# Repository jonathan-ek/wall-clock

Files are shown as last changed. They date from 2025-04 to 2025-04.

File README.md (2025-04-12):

# Wall clock
Smart wall clock that displays the electricity price
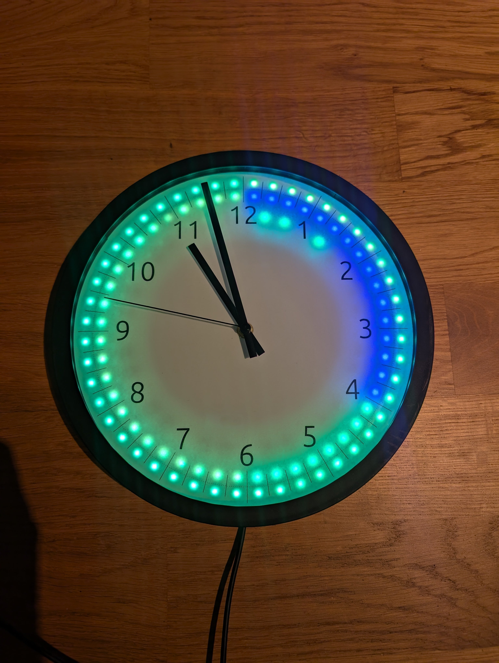
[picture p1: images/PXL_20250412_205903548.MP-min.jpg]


## Bill of material:
* Amazon Basics wall clock
* NeoPixel led strip 144 pixels per meter. Each pixel where 12 mm high and 7 mm wide
* Raspberry pi Pico W
* USB power supply + cable
* Transparent plastic sheet 300 x 300 x 3 mm
* Some black PLA or your material of choice
* Copper wire
* Solder

For a total cost of around 500-600 SEK plus some shipping

## Steps:
* Read the instructions and the comments
* Print the 3d printed parts
  * The fit of the printed parts isn't perfect, but it was good enough to not warrant any changes.
    You will need to print 4 of each 3d part.
    I welded the backplate parts together with a soldering iron, and some more filament.
    The other parts I just added a bit of glue between them and a round of electrical tape around the piece.
 
* Cut the LED strip in pieces so that there is one led per piece
* Print the LED placement guide and glue it to the backplate
* Glue the LEDs to the placement guide
* Solder the wires to the LEDs (this will take a while)
  * I would suggest testing the work as you go, so that you don't have to redo the whole thing if something goes wrong.
  * Start at 12 o'clock and go clockwise around the clock, after the outer ring is done, go from the last led to the inner ring and repeat
* Solder the wires to the Pico W, I used GP0, VBUS and GND
* Cut the plastic sheet to size
* Print the clock face and drill a 8 mm hole in the middel through the face and the plastic sheet
* Assemble the clock
  * Fasten the clock face to the plastic sheet with a few small tape pieces on the edges
  * Add the clock mechanism to the plastic sheet and reattach the clock hands
  * Then add the parts in the correct order:
    * Glass
    * Glass holder
    * Clock face
    * Backplate with LEDs
    * Outer ring
* Glue the Pico W to the backplate so that it is still accessible but not sticking out too much so it hits the wall.
* Melt a hole in the side of the clock housing for the power cable
* Optional glue the cable to the backplate so it doesn't move around too much
* Upload the code to the Pico W
* Add the home assistant file as a [python script](https://www.home-assistant.io/integrations/python_script/) and adjust it to your needs and sensors.

# Images:
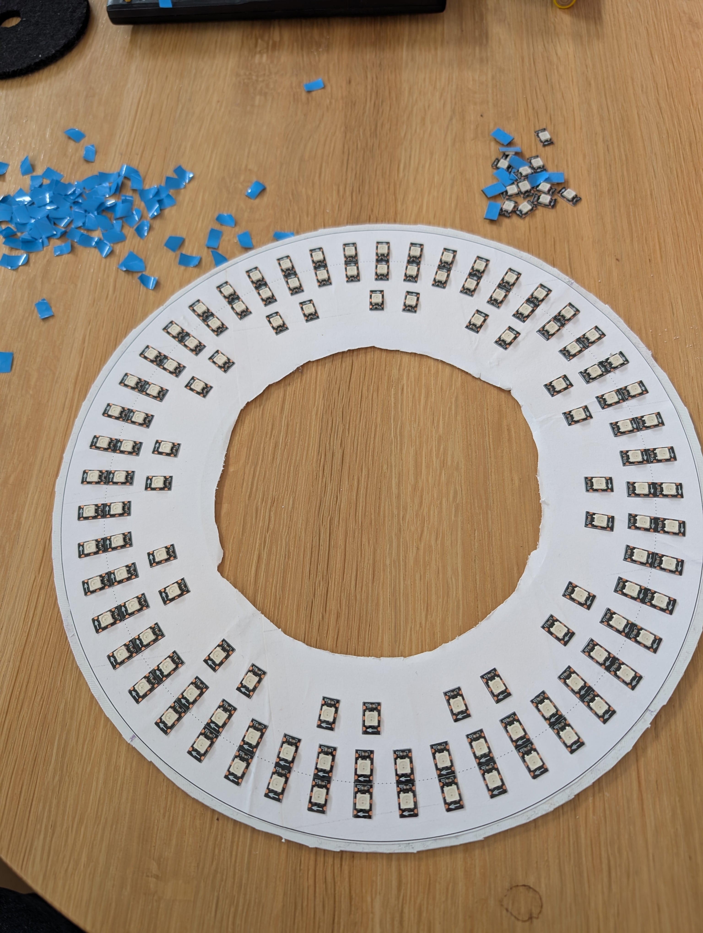
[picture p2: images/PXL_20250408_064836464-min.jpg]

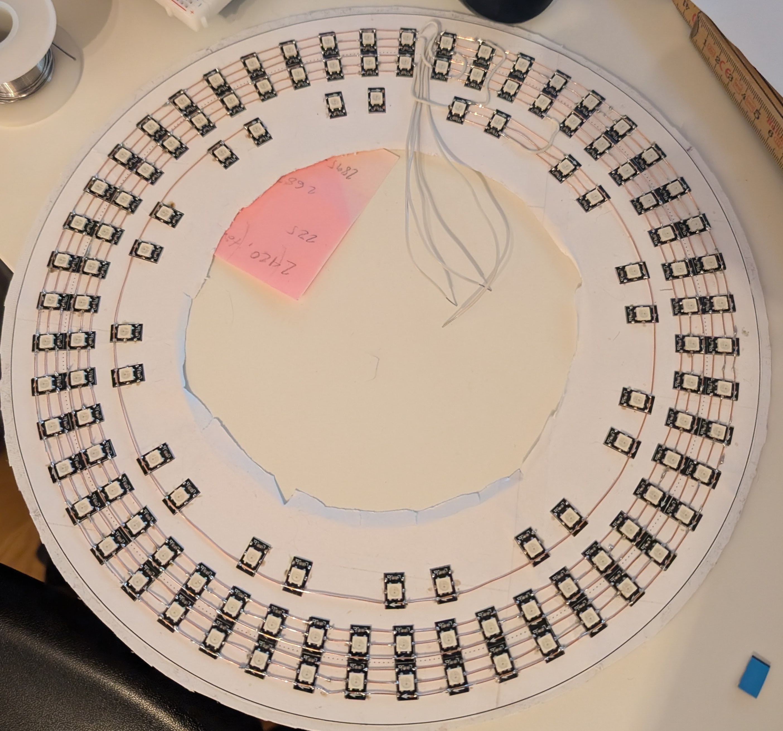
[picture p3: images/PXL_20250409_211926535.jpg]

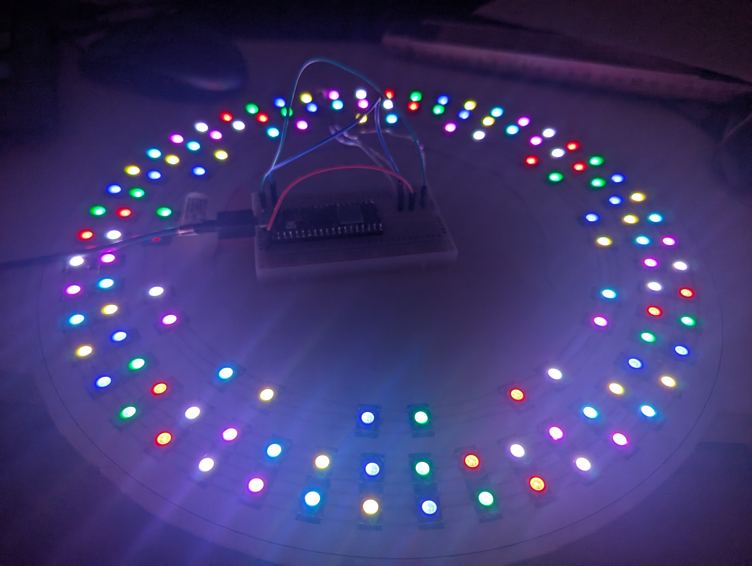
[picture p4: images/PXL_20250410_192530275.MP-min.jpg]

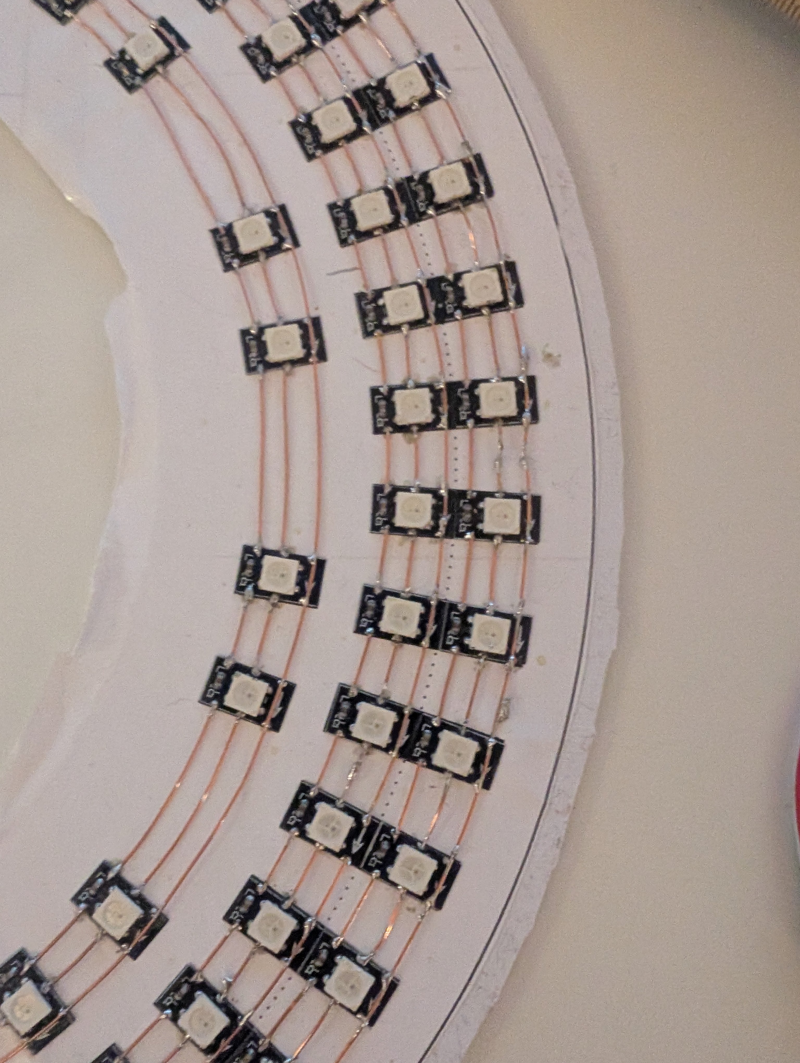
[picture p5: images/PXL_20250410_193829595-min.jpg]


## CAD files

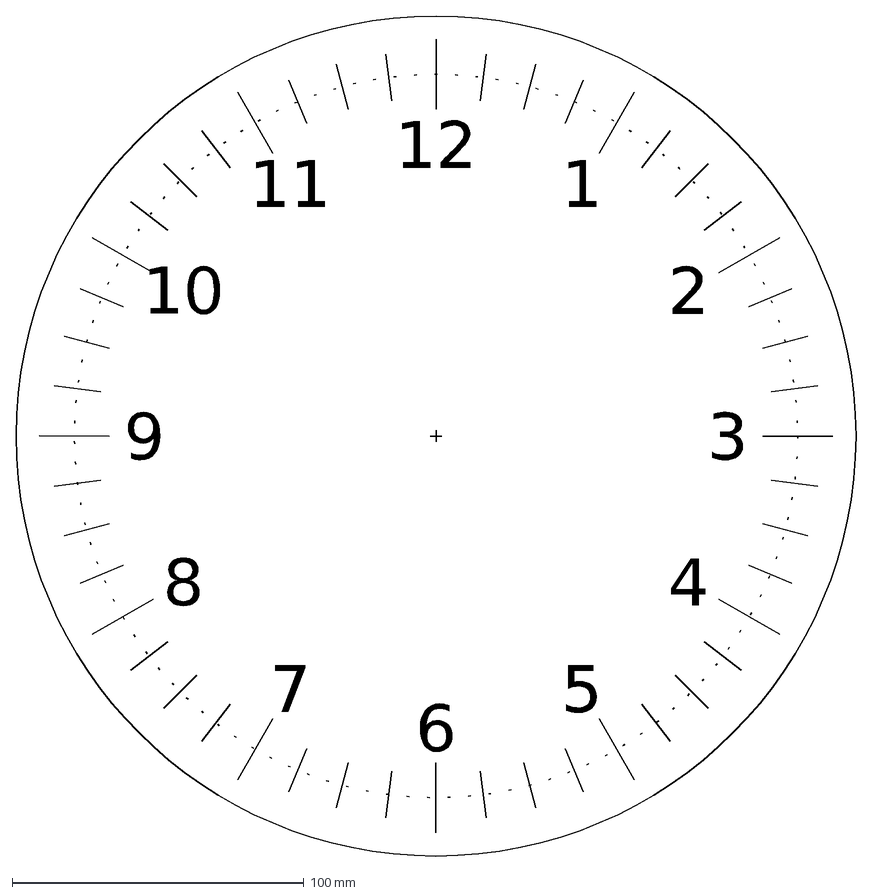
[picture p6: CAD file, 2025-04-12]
CAD-files/clock.dxf
12
11
10
9
8
7
6
5
4
3
2
1

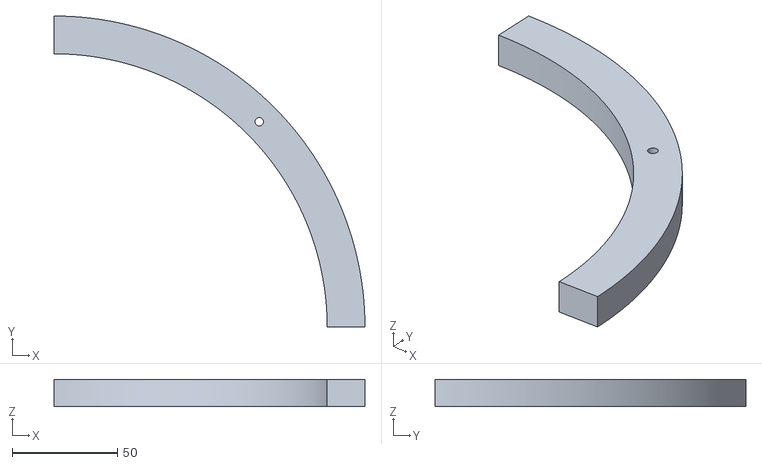
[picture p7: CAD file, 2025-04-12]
Output/outer_ring.stl
148.0 x 148.0 x 13.0

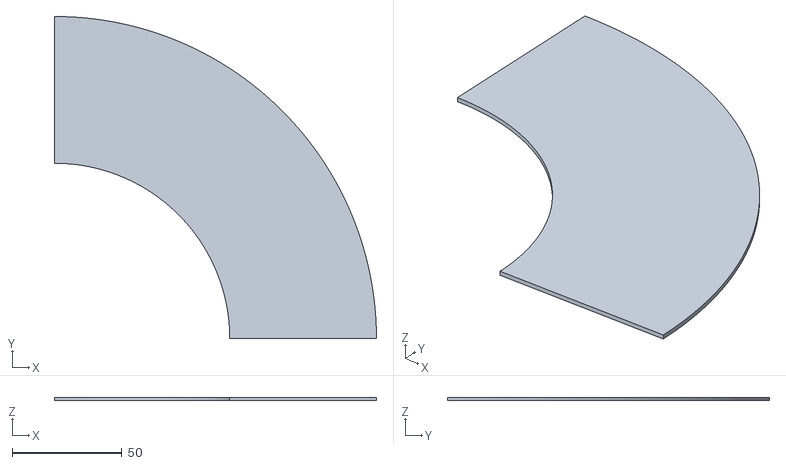
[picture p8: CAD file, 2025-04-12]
Output/back_plate.stl
147.0 x 147.0 x 1.50

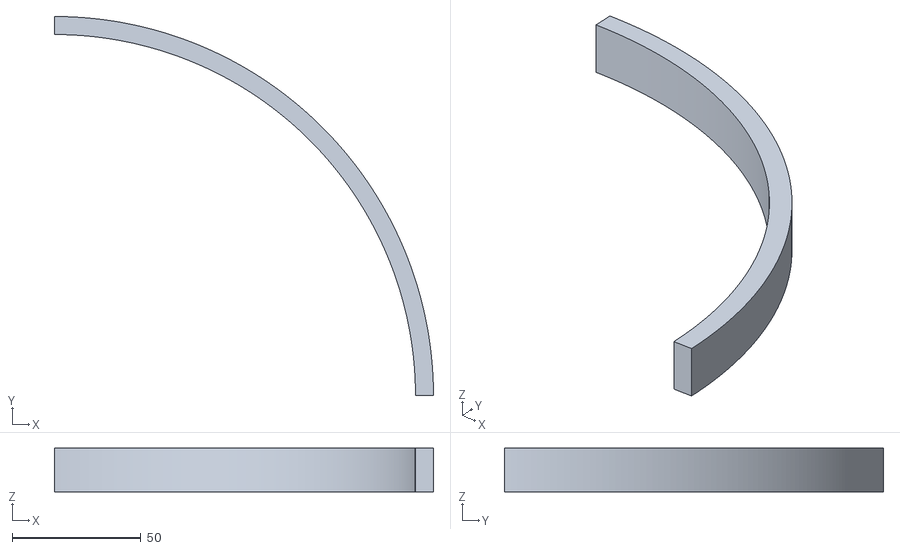
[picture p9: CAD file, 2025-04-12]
Output/glas_holder.stl
147.0 x 147.0 x 17.0

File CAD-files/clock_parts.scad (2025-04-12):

outer_dia = 296;

module glas_holder(){
    difference() {
        difference() {
            cylinder(17,r=outer_dia/2,$fn=360);
            translate([0,0,-1]){
                cylinder(19,r=280/2,$fn=720);
            }
        }
        union() {
            translate([-151,-151,-1]){
                cube([151,301,20]);
            }
            translate([-151,-151,-1]){
                cube([301,151,20]);
            }
        }
    }
}

module front_plate(){
    difference() {
        difference() {
            cylinder(1.5,r=outer_dia/2,$fn=360);
            translate([0,0,-1]){
                cylinder(19,r=8/2,$fn=720);
            }
        }
        union() {
            translate([-151,-151,-1]){
                cube([151,301,20]);
            }
            translate([-151,-151,-1]){
                cube([301,151,20]);
            }
        }
    }
}

module back_plate(){
    difference() {
        difference() {
            cylinder(1.5,r=outer_dia/2,$fn=360);
            translate([0,0,-1]){
                cylinder(19,r=160/2,$fn=720);
            }
        }
        union() {
            translate([-151,-151,-1]){
                cube([151,301,20]);
            }
            translate([-151,-151,-1]){
                cube([301,151,20]);
            }
        }
    }
}

module outer_ring(){
    difference() {
        difference() {
            cylinder(13,r=outer_dia/2,$fn=360);
            translate([0,0,-1]){
                cylinder(19,r=260/2,$fn=720);
                translate([(outer_dia/2)*0.66,(outer_dia/2)*0.66,0]) {
                    
                    cylinder(19,r=2,$fn=100);
                }
            }
            
        }
        
        union() {
            translate([-151,-151,-1]){
                cube([151,301,20]);
            }
            translate([-151,-151,-1]){
                cube([301,151,20]);
            }
        }
    }
}

//glas_holder();
//front_plate();
//back_plate();
outer_ring();

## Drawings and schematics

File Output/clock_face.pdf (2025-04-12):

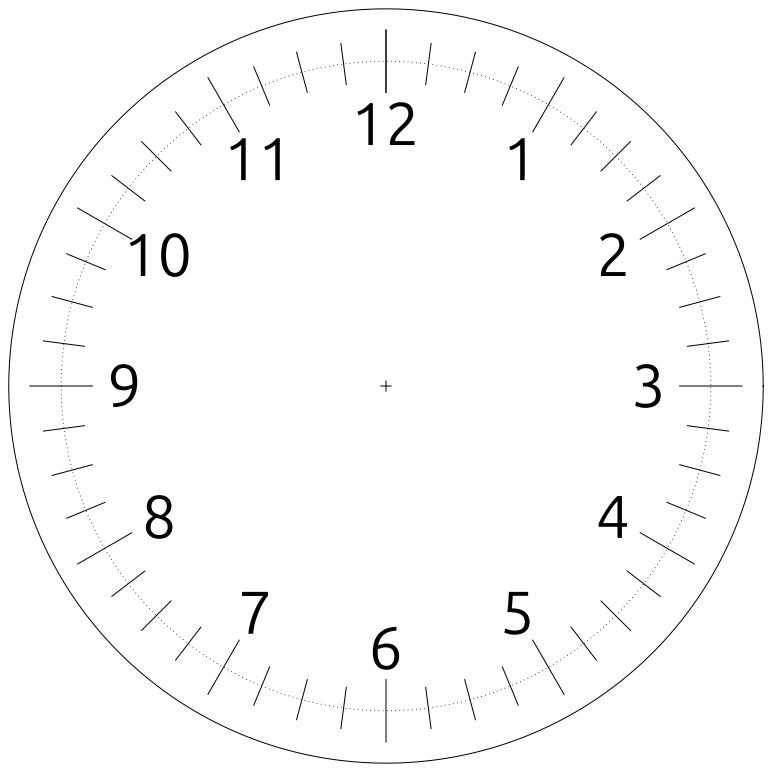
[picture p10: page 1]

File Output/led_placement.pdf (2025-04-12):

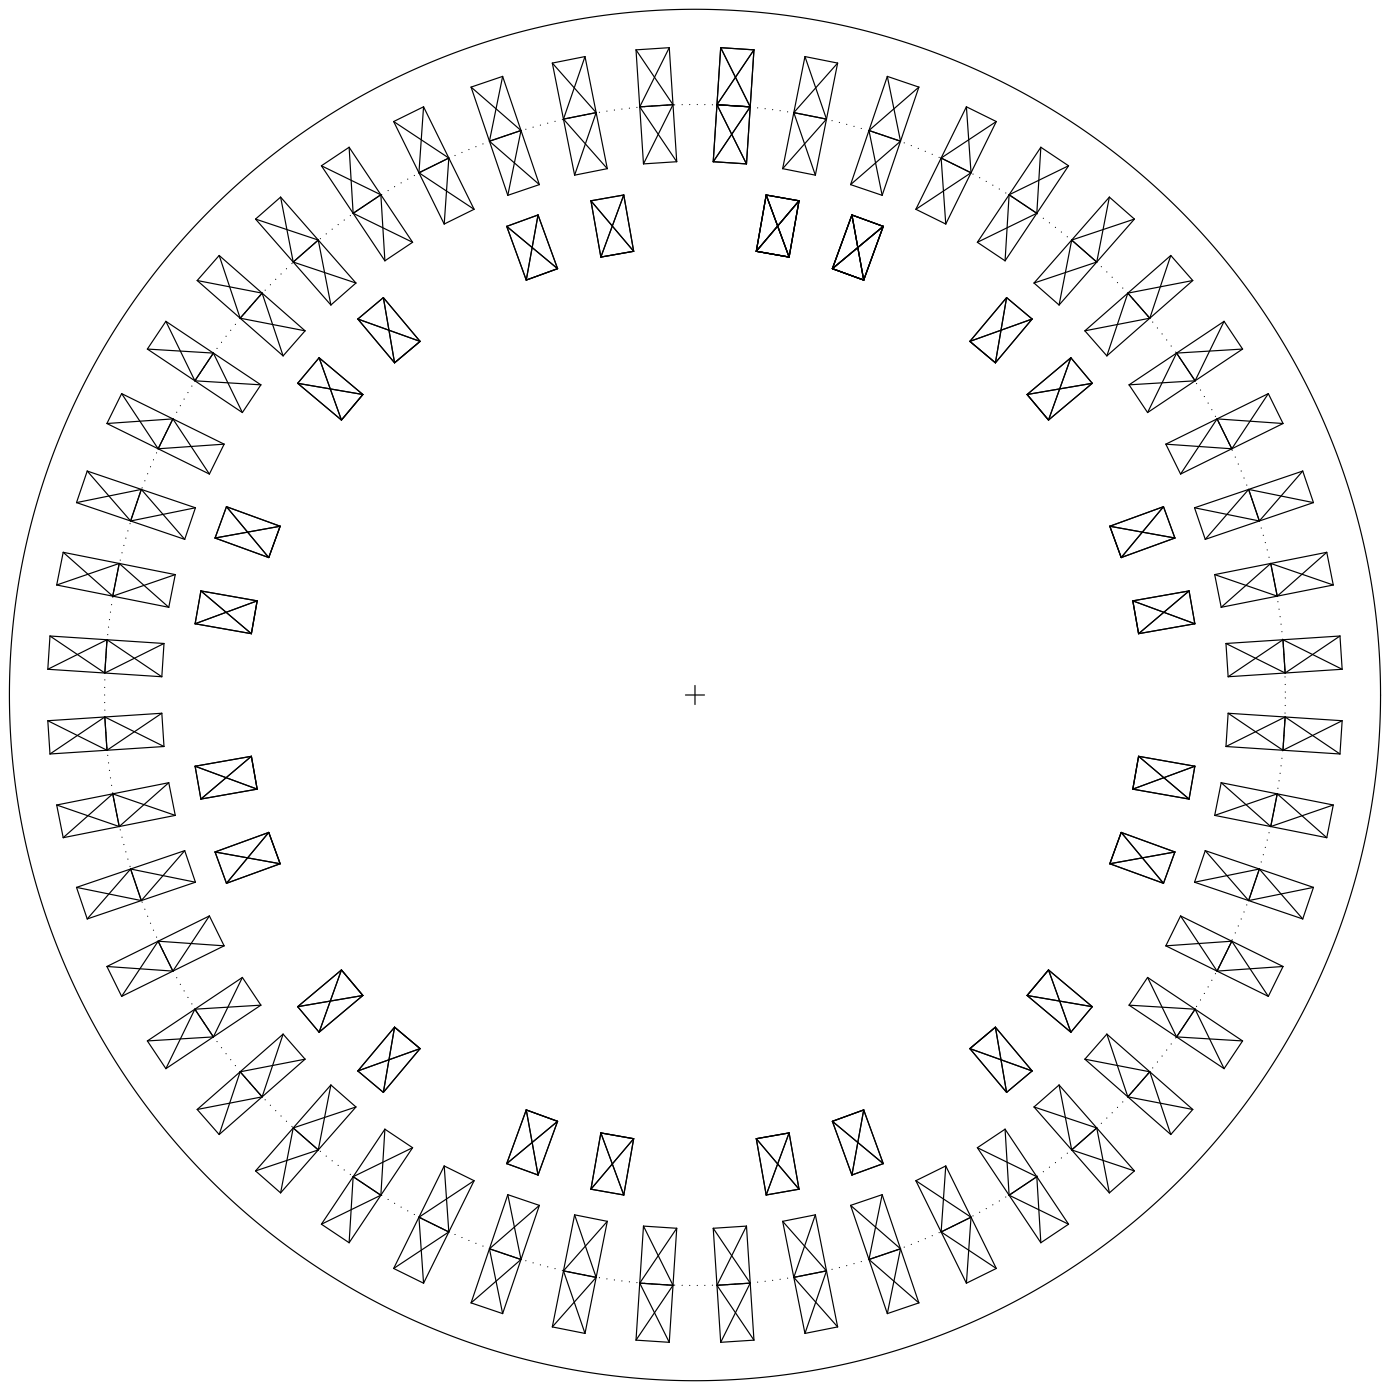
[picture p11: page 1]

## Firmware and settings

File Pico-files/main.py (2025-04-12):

import network
import uasyncio as asyncio
import urequests as requests
import neopixel
import machine
import time
from config import SSID, PSK, ENDPOINT, TOKEN
LED_PIN = 0  # GPIO pin
NUM_LEDS = 120

# SETUP NEOPIXEL
np = neopixel.NeoPixel(machine.Pin(LED_PIN), NUM_LEDS)

# GLOBAL STATE
current_state = [((0, 0, 0), "solid") for _ in range(NUM_LEDS)]

# CONNECT TO WIFI
def connect_wifi():
    wlan = network.WLAN(network.STA_IF)
    wlan.active(True)
    if not wlan.isconnected():
        print("Connecting to WiFi...")
        wlan.connect(SSID, PSK)
        while not wlan.isconnected():
            time.sleep(0.5)
    print("Connected:", wlan.ifconfig())

# UPDATE LEDS BASED ON STATE
def update_leds():
    for i, (rgb, mode) in enumerate(current_state):
        np[i] = rgb if mode == "solid" else (0, 0, 0)  # pulsing handled separately
    np.write()

# PULSING EFFECT TASK
async def pulsing_effect():
    while True:
        for brightness in list(range(0, 256, 15)) + list(range(255, -1, -15)):
            for i, (rgb, mode) in enumerate(current_state):
                if mode == "pulsing":
                    scaled = tuple(int(c * (brightness / 255)) for c in rgb)
                    np[i] = scaled
            np.write()
            await asyncio.sleep(0.05)

# FETCH COLORS FROM API
async def fetch_and_update():
    global current_state
    while True:
        try:
            print("Sending POST request...")
            response = requests.post(ENDPOINT, headers={
                "Authorization": f"Bearer {TOKEN}"
                })
            if response.status_code == 200:
                data = response.json().get("service_response", {}).get('data', [])
                if isinstance(data, list) and len(data) == NUM_LEDS:
                    current_state = data
                    update_leds()
                else:
                    print("Invalid response format.")
            else:
                print("Error:", response.status_code)
            response.close()
        except Exception as e:
            print("Request failed:", e)
        await asyncio.sleep(15)

# MAIN FUNCTION
async def main():
    connect_wifi()
    asyncio.create_task(pulsing_effect())
    await fetch_and_update()

# RUN
try:
    asyncio.run(main())
except KeyboardInterrupt:
    print("Interrupted by user, cleaning up...")
    # optional: turn off all LEDs on exit
    for i in range(NUM_LEDS):
        np[i] = (0, 0, 0)
    np.write()
